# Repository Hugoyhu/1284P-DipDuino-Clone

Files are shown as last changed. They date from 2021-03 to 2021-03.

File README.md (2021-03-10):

# 1284P-DipDuino-Clone
Small form factor 1284P Development Board inspired by AtomSoftTech's DipDuino(https://www.tindie.com/products/atomsoft/dipduino-12/).

Schematic was based off Dcelectr's 1284P Schematic(https://github.com/dcelectr/ATmega1284P_Board), and USB bridge schematic from Sparkfun(https://www.sparkfun.com/products/15096)

Designed with KiCAD EDA.

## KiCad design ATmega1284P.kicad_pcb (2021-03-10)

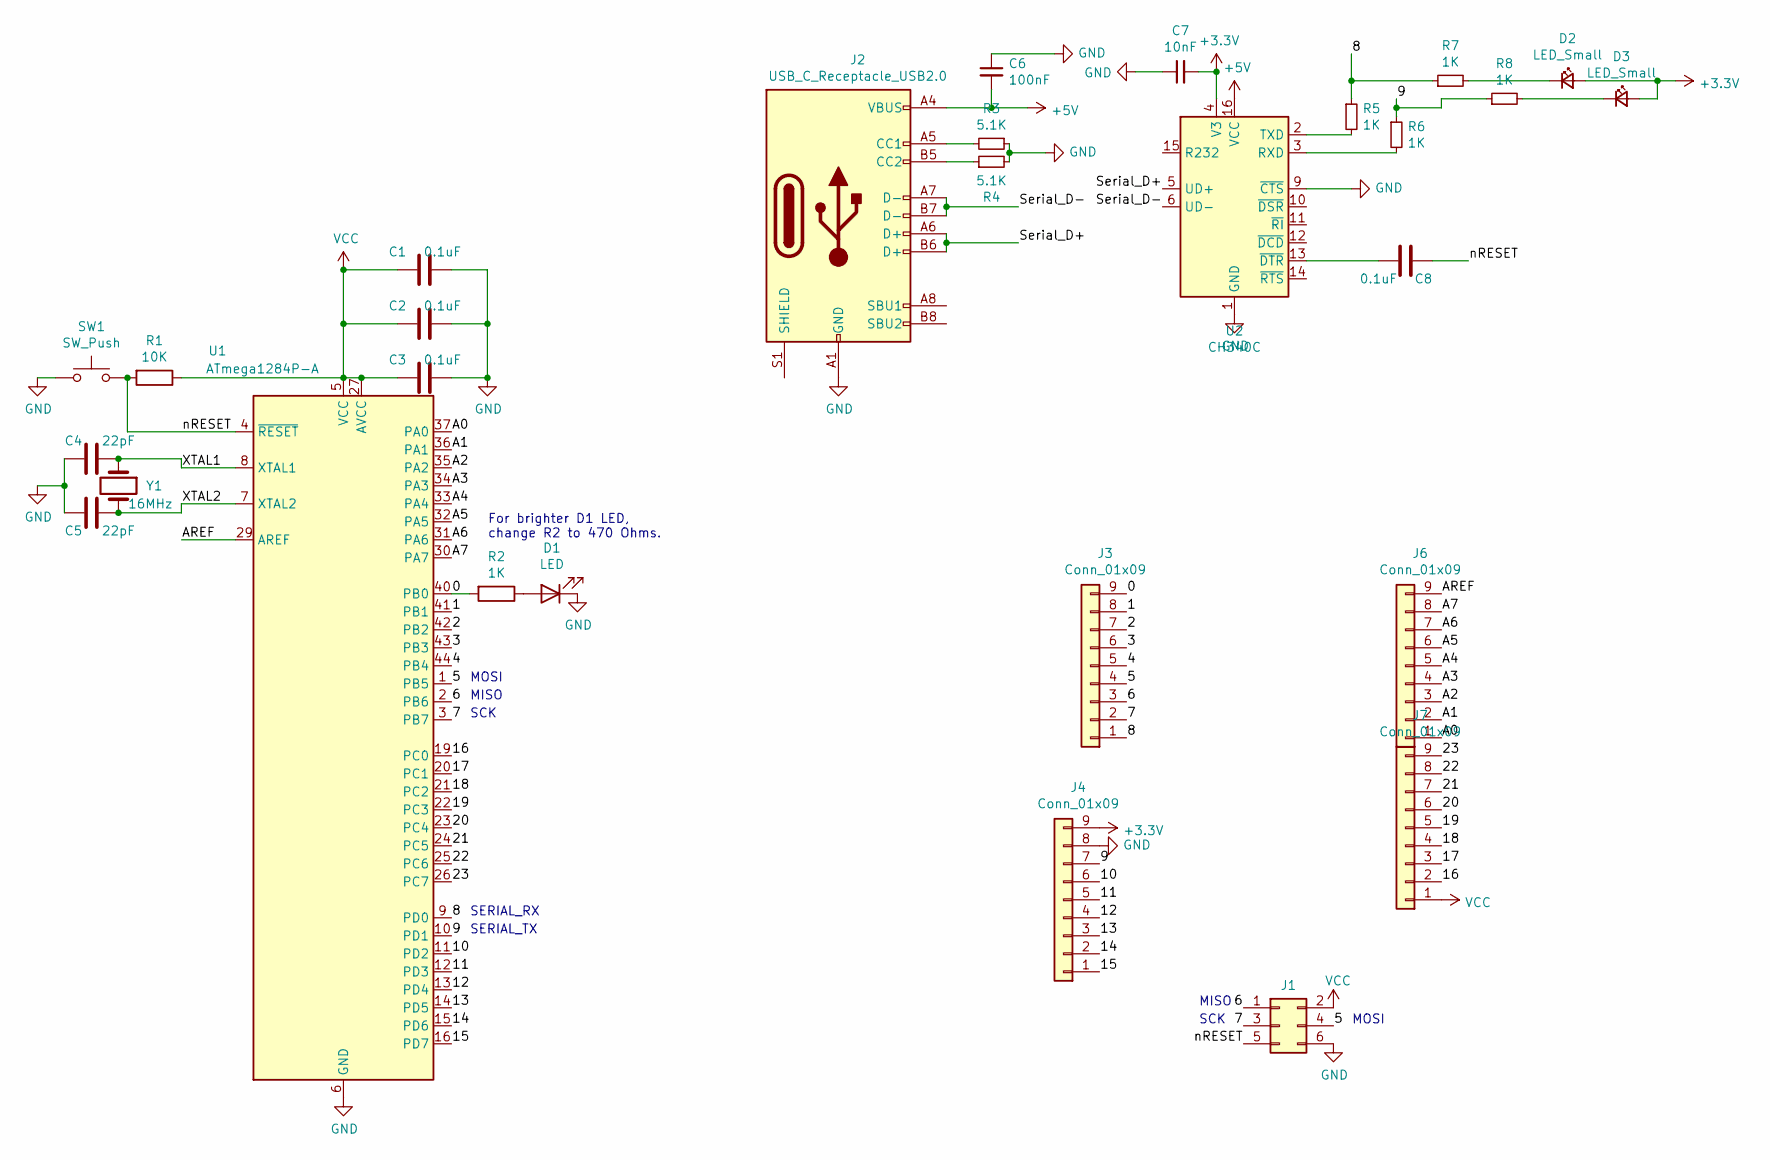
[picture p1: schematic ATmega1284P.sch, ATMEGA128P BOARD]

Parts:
C1, C2, C3, C8: 0.1uF; C_0805_2012Metric_Pad1.18x1.45mm_HandSolder
C4, C5: 22pF; C_0805_2012Metric_Pad1.18x1.45mm_HandSolder
C6: 100nF; C_0805_2012Metric_Pad1.18x1.45mm_HandSolder
C7: 10nF; C_0805_2012Metric_Pad1.18x1.45mm_HandSolder
D1: LED; LED_0805_2012Metric_Pad1.15x1.40mm_HandSolder
D2, D3: LED_Small; LED_0805_2012Metric_Pad1.15x1.40mm_HandSolder
J1: Conn_02x03_Odd_Even; PinHeader_2x03_P2.54mm_Vertical
J2: USB_C_Receptacle_USB2.0; GCT_USB4085-GF-A_REVA
J3, J4, J6, J7: Conn_01x09; PinSocket_1x09_P2.54mm_Vertical
R1: 10K; R_0805_2012Metric_Pad1.20x1.40mm_HandSolder
R2: 1K; R_0805_2012Metric_Pad1.20x1.40mm_HandSolder
R3, R4: 5.1K; R_0805_2012Metric_Pad1.20x1.40mm_HandSolder
R5, R6, R7, R8: 1K; R_0603_1608Metric_Pad0.98x0.95mm_HandSolder
SW1: SW_Push; SW_SPST_B3U-1000P
U1: ATmega1284P-A; TQFP-44_10x10mm_P0.8mm
U2: CH340C; SOIC-16_3.9x9.9mm_P1.27mm
Y1: 16MHz; Crystal_SMD_5032-2Pin_5.0x3.2mm_HandSoldering

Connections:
+3V3: C7.2, D2.2 (A), D3.2 (A), J4.9, U2.4 (V3)
+5V: C6.2, J2.A4 (VBUS), J2.A9 (VBUS), J2.B4 (VBUS), J2.B9 (VBUS), U2.16 (VCC)
/0: J3.9, R2.2, U1.40 (PB0)
/1: J3.8, U1.41 (PB1)
/2: J3.7, U1.42 (PB2)
/3: J3.6, U1.43 (PB3)
/4: J3.5, U1.44 (PB4)
/5: J1.4, J3.4, U1.1 (PB5)
/6: J1.1, J3.3, U1.2 (PB6)
/7: J1.3, J3.2, U1.3 (PB7)
/8: J3.1, R5.1, R7.1, U1.9 (PD0)
/9: J4.7, R6.1, R8.1, U1.10 (PD1)
/10: J4.6, U1.11 (PD2)
/11: J4.5, U1.12 (PD3)
/12: J4.4, U1.13 (PD4)
/13: J4.3, U1.14 (PD5)
/14: J4.2, U1.15 (PD6)
/15: J4.1, U1.16 (PD7)
/16: J7.2, U1.19 (PC0)
/17: J7.3, U1.20 (PC1)
/18: J7.4, U1.21 (PC2)
/19: J7.5, U1.22 (PC3)
/20: J7.6, U1.23 (PC4)
/21: J7.7, U1.24 (PC5)
/22: J7.8, U1.25 (PC6)
/23: J7.9, U1.26 (PC7)
/A0: J6.1, U1.37 (PA0)
/A1: J6.2, U1.36 (PA1)
/A2: J6.3, U1.35 (PA2)
/A3: J6.4, U1.34 (PA3)
/A4: J6.5, U1.33 (PA4)
/A5: J6.6, U1.32 (PA5)
/A6: J6.7, U1.31 (PA6)
/A7: J6.8, U1.30 (PA7)
/AREF: J6.9, U1.29 (AREF)
/Serial_D+: J2.A6 (D+), J2.B6 (D+), U2.5 (UD+)
/Serial_D-: J2.A7 (D-), J2.B7 (D-), U2.6 (UD-)
/XTAL1: C4.1, U1.8 (XTAL1), Y1.1
/XTAL2: C5.1, U1.7 (XTAL2), Y1.2
/nRESET: C8.2, J1.5, R1.2, SW1.2, U1.4 (~RESET)
GND: C1.1, C2.1, C3.1, C4.2, C5.2, C6.1, C7.1, D1.1 (K), J1.6, J2.A1 (GND), J2.A12 (GND), J2.B1 (GND), J2.B12 (GND), J4.8, R3.1, R4.2, SW1.1, U1.6 (GND), U1.18 (GND), U1.28 (GND), U1.39 (GND), U2.1 (GND), U2.9 (~CTS)
unnamed: C8.1, U2.13 (~DTR)
unnamed: D1.2 (A), R2.1
unnamed: D2.1 (K), R7.2
unnamed: D3.1 (K), R8.2
unnamed: J2.A5 (CC1), R3.2
unnamed: J2.B5 (CC2), R4.1
unnamed: R5.2, U2.2 (TXD)
unnamed: R6.2, U2.3 (RXD)
VCC: C1.2, C2.2, C3.2, J1.2, J7.1, R1.1, U1.5 (VCC), U1.17 (VCC), U1.27 (AVCC), U1.38 (VCC)

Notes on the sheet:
MOSI
MISO
SCK
SERIAL_RX
SERIAL_TX
For brighter D1 LED, change R2 to 470 Ohms.

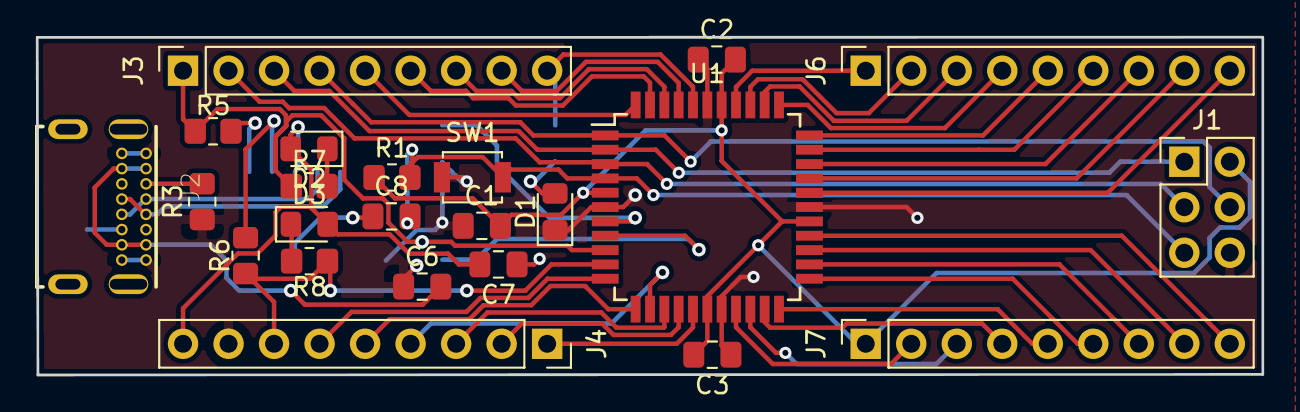
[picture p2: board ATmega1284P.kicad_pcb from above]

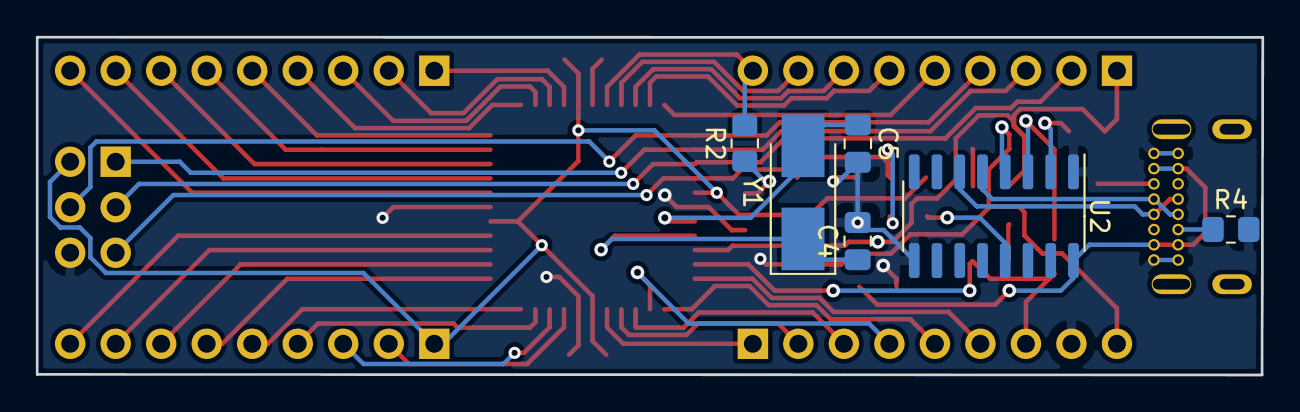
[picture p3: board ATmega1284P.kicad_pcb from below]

Board: 2 copper layers, 68.4 x 18.9 mm, 29 parts (6 on the bottom side), 50 nets.
